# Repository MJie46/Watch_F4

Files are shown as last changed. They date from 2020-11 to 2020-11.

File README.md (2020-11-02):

# Watch_F4
>
#### 尺寸 40x36mm
#### STM32F405RGT6
#### IP5306+MP20045
#### MPU6050
#### W25Q128JVS
#### 蓝牙主从一体模块
#### 1.44寸SPI屏
#### 背面MAX30102，用作血氧检测
#### 背面引出4个按钮引脚

### 3D打印外壳
##### 本来想做成像外面卖的智能手表使用触电充电，再配上一个充电的底壳，但尝试后发现手工焊接接触平面很难4个触点在同一平面上，改用type-c接口，通过type-c烧录和串口调试

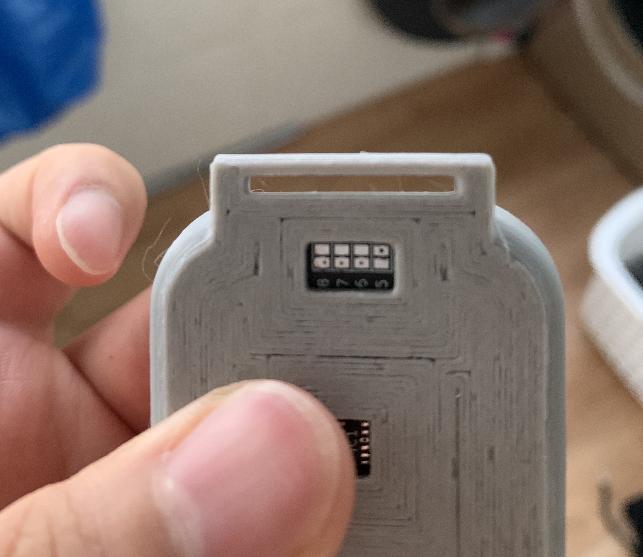
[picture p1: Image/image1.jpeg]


####第一版做好的大概，码代码中...
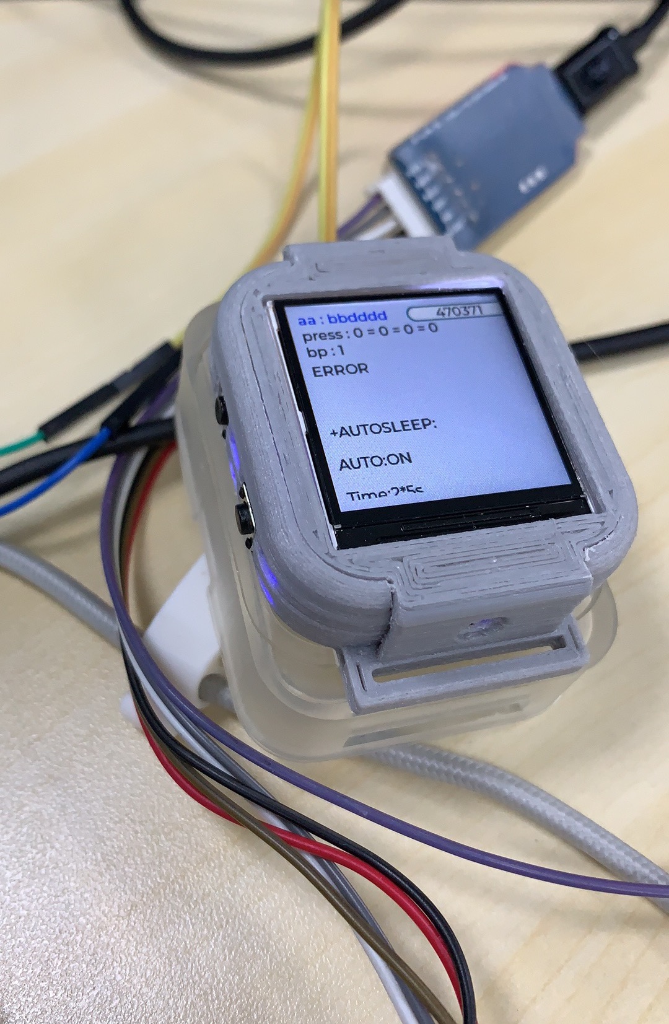
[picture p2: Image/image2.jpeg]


### 系统FreeRTOS，具体功能还没完善，待填...

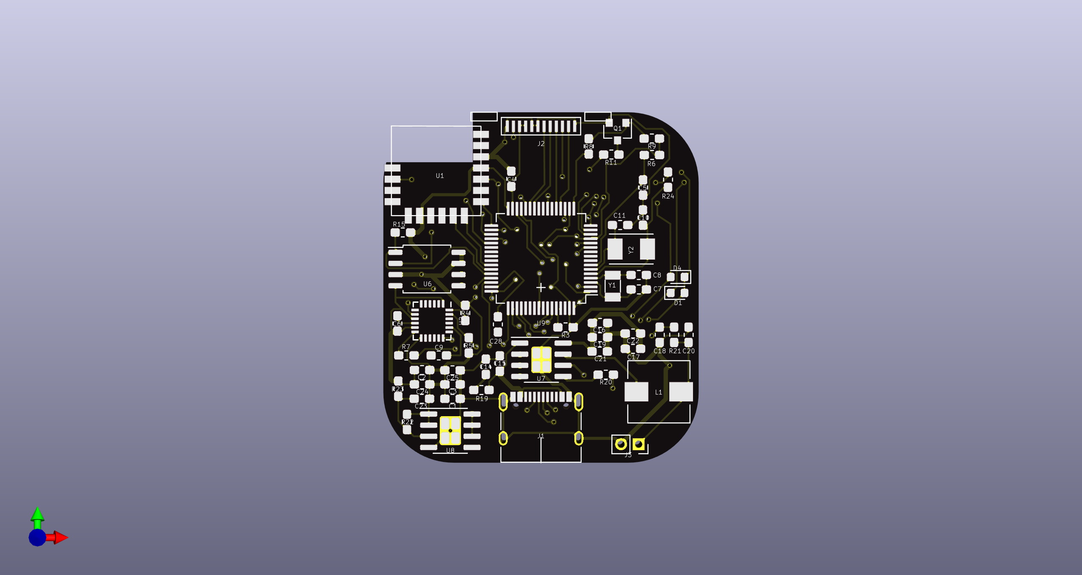
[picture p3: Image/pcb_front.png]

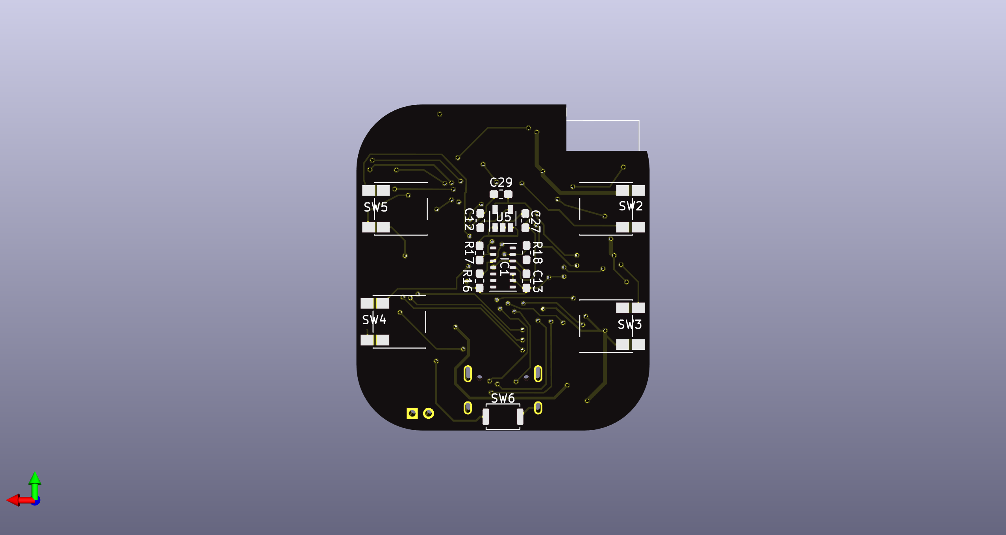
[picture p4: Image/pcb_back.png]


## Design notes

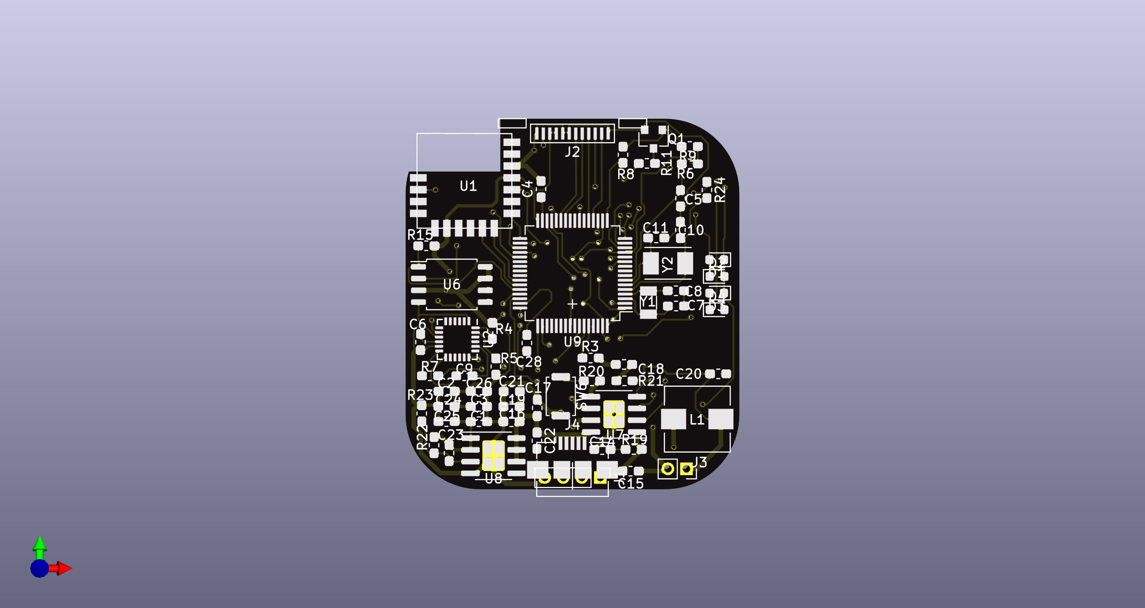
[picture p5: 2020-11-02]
Watch_F4.png

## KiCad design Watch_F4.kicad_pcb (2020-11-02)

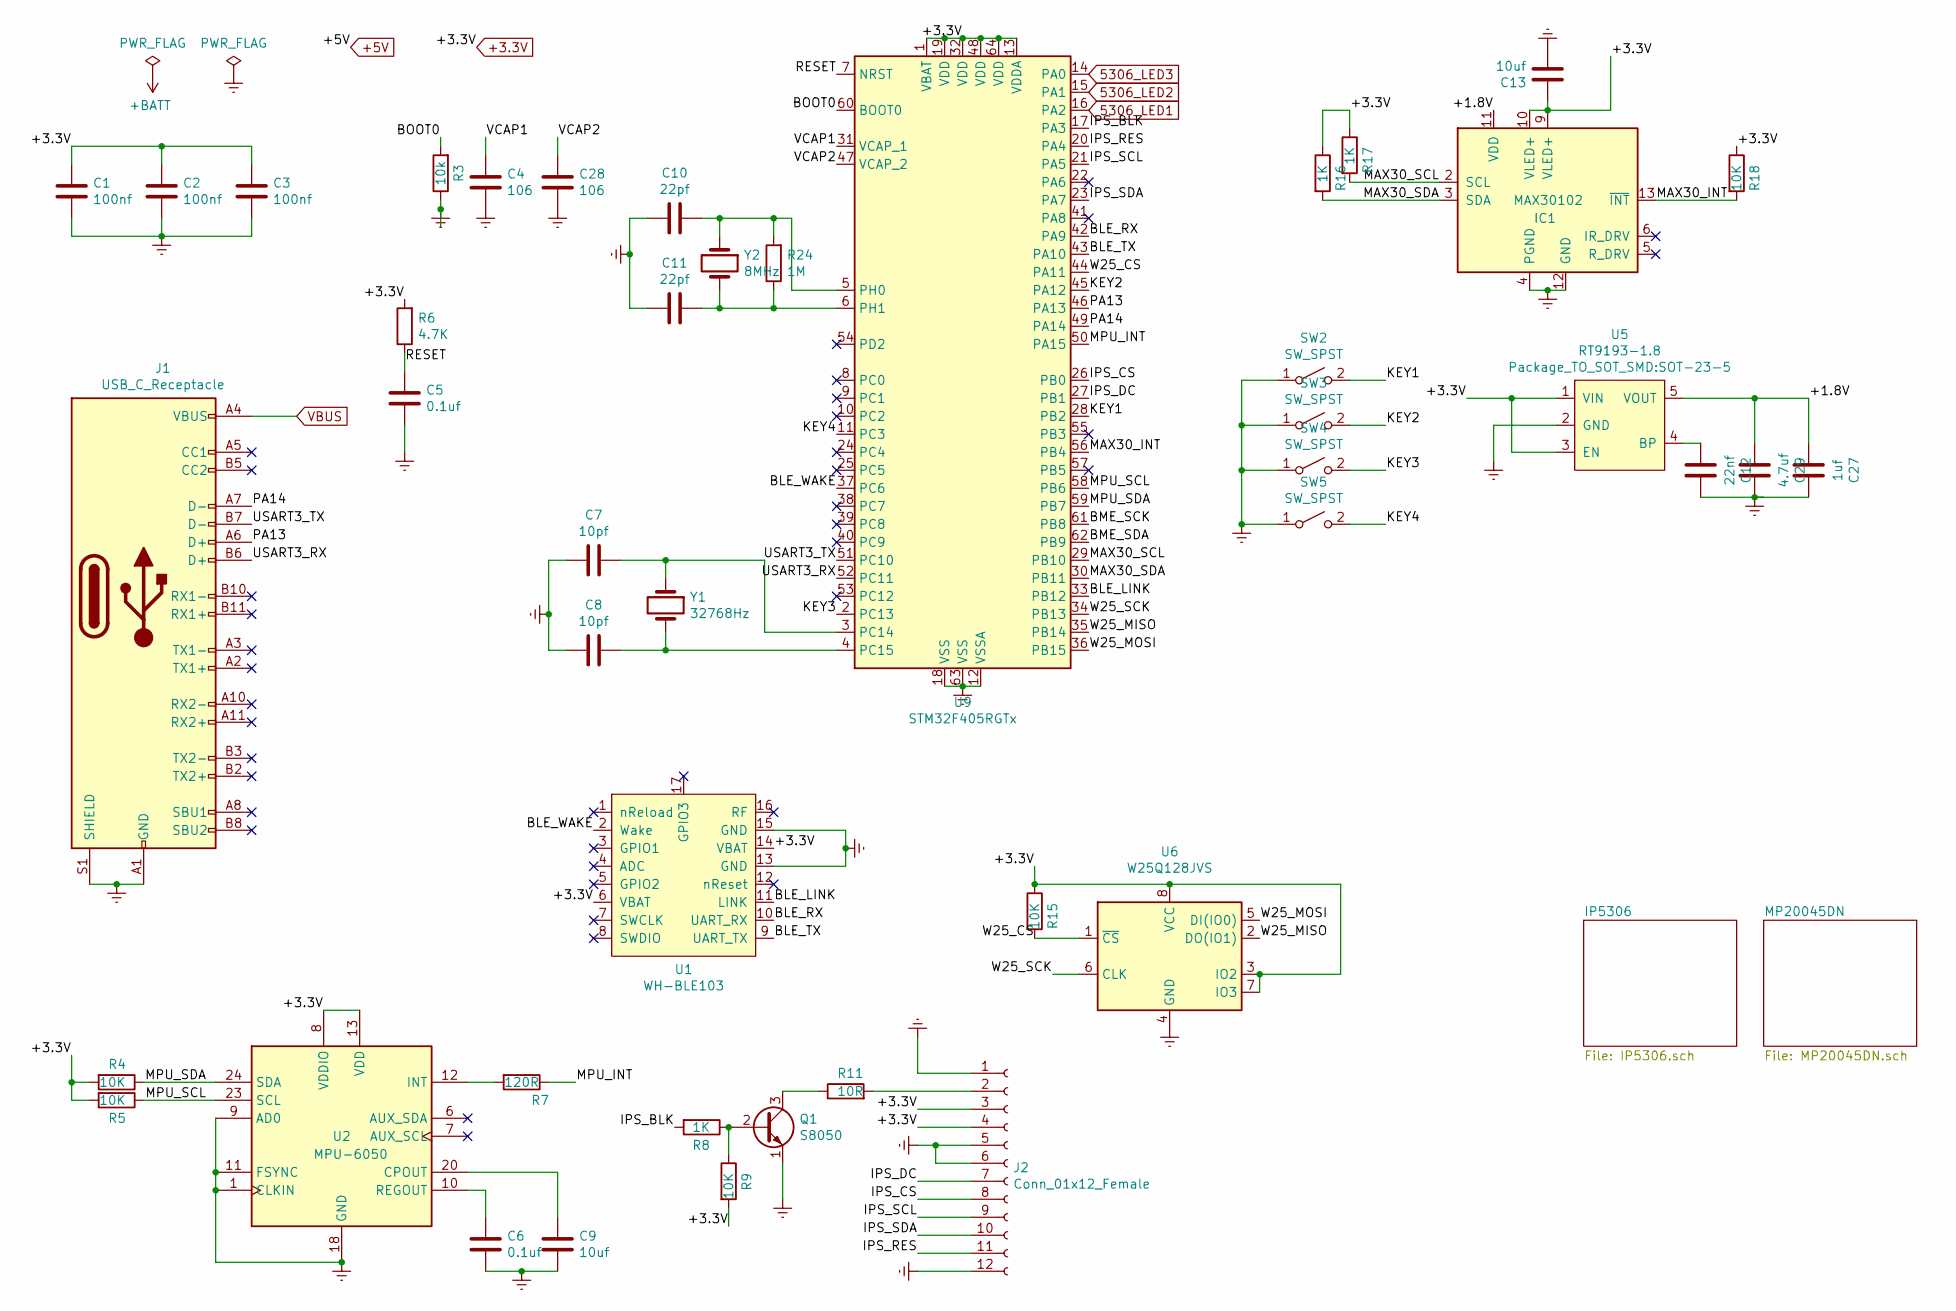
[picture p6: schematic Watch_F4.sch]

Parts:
C1, C2, C3: 100nf; C_0603_1608Metric_Pad1.05x0.95mm_HandSolder
C4, C28: 106; C_0603_1608Metric_Pad1.05x0.95mm_HandSolder
C5, C6: 0.1uf; C_0603_1608Metric_Pad1.05x0.95mm_HandSolder
C7, C8: 10pf; C_0603_1608Metric_Pad1.05x0.95mm_HandSolder
C9, C13: 10uf; C_0603_1608Metric_Pad1.05x0.95mm_HandSolder
C10, C11: 22pf; C_0603_1608Metric_Pad1.05x0.95mm_HandSolder
C12: 22nf; C_0603_1608Metric_Pad1.05x0.95mm_HandSolder
C27: 1uf; C_0603_1608Metric_Pad1.05x0.95mm_HandSolder
C29: 4.7uf; C_0603_1608Metric_Pad1.05x0.95mm_HandSolder
IC1: MAX30102; Maxim_OLGA-14_3.3x5.6mm_P0.8mm
J1: USB_C_Receptacle; USB_C_Receptacle_XKB_U262-16XN-4BVC11
J2: Conn_01x12_Female; FPC1x12-0.7
Q1: S8050; SOT-23-s8050
R3: 10k; R_0603_1608Metric_Pad1.05x0.95mm_HandSolder
R4, R5, R9, R15, R18: 10K; R_0603_1608Metric_Pad1.05x0.95mm_HandSolder
R6: 4.7K; R_0603_1608Metric_Pad1.05x0.95mm_HandSolder
R7: 120R; R_0603_1608Metric_Pad1.05x0.95mm_HandSolder
R8, R16, R17: 1K; R_0603_1608Metric_Pad1.05x0.95mm_HandSolder
R11: 10R; R_0603_1608Metric_Pad1.05x0.95mm_HandSolder
R24: 1M; R_0603_1608Metric_Pad1.05x0.95mm_HandSolder
SW2, SW3, SW4, SW5: SW_SPST; SW_SPST_PTS645
U1: WH-BLE103
U2: MPU-6050; InvenSense_QFN-24_4x4mm_P0.5mm
U5: RT9193-1.8; SOT-23-5
U6: W25Q128JVS; SOIC-8_5.23x5.23mm_P1.27mm
U9: STM32F405RGTx; LQFP-64_10x10mm_P0.5mm
Y1: 32768Hz; Crystal_SMD_3215-2Pin_3.2x1.5mm
Y2: 8MHz; Crystal_SMD_TXC_7A-2Pin_5x3.2mm

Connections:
5306_LED1: U9.16 (PA2); also elsewhere on the board
5306_LED2: U9.15 (PA1); also elsewhere on the board
5306_LED3: U9.14 (PA0); also elsewhere on the board
+3.3V: C1.1, C2.1, C3.1, C13.1, IC1.9 (VLED+), IC1.10 (VLED+), J2.3, J2.4, R4.2, R5.2, R6.2, R9.2, R15.1, R16.1, R17.1, R18.1, U1.6 (VBAT), U1.14 (VBAT), U2.8 (VDDIO), U2.13 (VDD), U5.1 (VIN), U5.3 (EN), U6.3 (IO2), U6.7 (IO3), U6.8 (VCC), U9.1 (VBAT), U9.13 (VDDA), U9.19 (VDD), U9.32 (VDD), U9.48 (VDD), U9.64 (VDD); also elsewhere on the board
/+1.8V: C27.2, C29.2, IC1.11 (VDD), U5.5 (VOUT)
/BLE_LINK: U1.11 (LINK), U9.33 (PB12)
/BLE_RX: U1.10 (UART_RX), U9.42 (PA9)
/BLE_TX: U1.9 (UART_TX), U9.43 (PA10)
/BLE_WAKE: U1.2 (Wake), U9.37 (PC6)
/BME_SCK: U9.61 (PB8)
/BME_SDA: U9.62 (PB9)
/BOOT0: R3.2, U9.60 (BOOT0)
/IPS_BLK: R8.2, U9.17 (PA3)
/IPS_CS: J2.8, U9.26 (PB0)
/IPS_DC: J2.7, U9.27 (PB1)
/IPS_RES: J2.11, U9.20 (PA4)
/IPS_SCL: J2.9, U9.21 (PA5)
/IPS_SDA: J2.10, U9.23 (PA7)
/KEY1: SW2.2 (B), U9.28 (PB2)
/KEY2: SW3.2 (B), U9.45 (PA12)
/KEY3: SW4.2 (B), U9.2 (PC13)
/KEY4: SW5.2 (B), U9.11 (PC3)
/MAX30_INT: IC1.13 (~INT), R18.2, U9.56 (PB4)
/MAX30_SCL: IC1.2 (SCL), R17.2, U9.29 (PB10)
/MAX30_SDA: IC1.3 (SDA), R16.2, U9.30 (PB11)
/MPU_INT: R7.1, U9.50 (PA15)
/MPU_SCL: R5.1, U2.23 (SCL), U9.58 (PB6)
/MPU_SDA: R4.1, U2.24 (SDA), U9.59 (PB7)
/PA13: J1.A6 (D+), U9.46 (PA13)
/PA14: J1.A7 (D-), U9.49 (PA14)
/RESET: C5.1, R6.1, U9.7 (NRST)
/UART4_RX: J1.B6 (D+), U9.52 (PC11)
/UART4_TX: J1.B7 (D-), U9.51 (PC10)
/VCAP1: C4.1, U9.31 (VCAP_1)
/VCAP2: C28.1, U9.47 (VCAP_2)
/W25_CS: R15.2, U6.1 (~CS), U9.44 (PA11)
/W25_MISO: U6.2 (DO(IO1)), U9.35 (PB14)
/W25_MOSI: U6.5 (DI(IO0)), U9.36 (PB15)
/W25_SCK: U6.6 (CLK), U9.34 (PB13)
Earth: C1.2, C2.2, C3.2, C4.2, C5.2, C6.2, C7.2, C8.2, C9.2, C10.2, C11.2, C12.1, C13.2, C27.1, C28.2, C29.1, IC1.4 (PGND), IC1.12 (GND), J1.A1 (GND), J1.A12 (GND), J1.B1 (GND), J1.B12 (GND), J1.S1 (SHIELD), J2.1, J2.5, J2.6, J2.12, Q1.1 (E), R3.1, SW2.1 (A), SW3.1 (A), SW4.1 (A), SW5.1 (A), U1.13 (GND), U1.15 (GND), U2.1 (CLKIN), U2.9 (AD0), U2.11 (FSYNC), U2.18 (GND), U5.2 (GND), U6.4 (GND), U9.12 (VSSA), U9.18 (VSS), U9.63 (VSS); also elsewhere on the board
unnamed: C6.1, U2.10 (REGOUT)
unnamed: C7.1, U9.3 (PC14), Y1.1
unnamed: C8.1, U9.4 (PC15), Y1.2
unnamed: C9.1, U2.20 (CPOUT)
unnamed: C10.1, R24.2, U9.5 (PH0), Y2.1
unnamed: C11.1, R24.1, U9.6 (PH1), Y2.2
unnamed: C12.2, U5.4 (BP)
unnamed: J2.2, R11.2
unnamed: Q1.2 (B), R8.1, R9.1
unnamed: Q1.3 (C), R11.1
unnamed: R7.2, U2.12 (INT)
VBUS: J1.A4 (VBUS), J1.A9 (VBUS), J1.B4 (VBUS), J1.B9 (VBUS); also elsewhere on the board

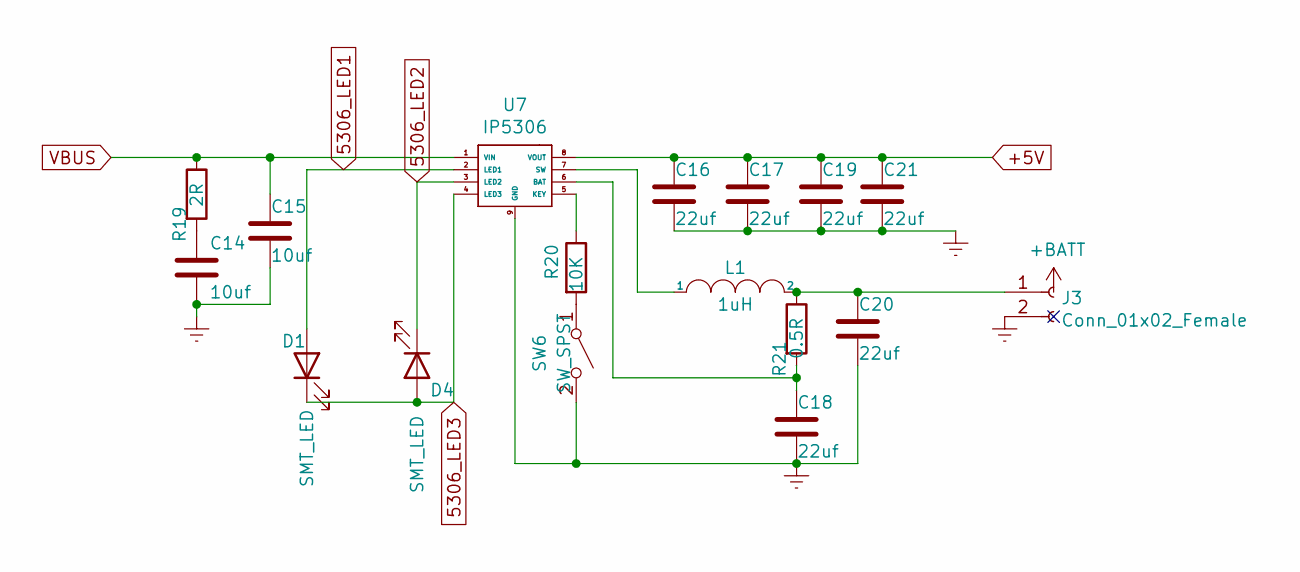
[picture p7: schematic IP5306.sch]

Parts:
C14, C15: 10uf; C_0603_1608Metric_Pad1.05x0.95mm_HandSolder
C16, C17, C18, C19, C20, C21: 22uf; C_0603_1608Metric_Pad1.05x0.95mm_HandSolder
D1, D4: SMT_LED; LED_0603_1608Metric
J3: Conn_01x02_Female; PinSocket_1x02_P2.00mm_Vertical
L1: 1uH; L_Wuerth_HCI-7030
R19: 2R; R_0603_1608Metric_Pad1.05x0.95mm_HandSolder
R20: 10K; R_0603_1608Metric_Pad1.05x0.95mm_HandSolder
R21: 0.5R; R_0603_1608Metric_Pad1.05x0.95mm_HandSolder
SW6: SW_SPST; SW_Push_SPST_NO_Alps_SKRK
U7: IP5306; SOIC-8-1EP_3.9x4.9mm_P1.27mm_EP2.29x3mm

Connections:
5306_LED1: D1.2 (A), U7.2 (LED1); also elsewhere on the board
5306_LED2: D4.1 (K), U7.3 (LED2); also elsewhere on the board
5306_LED3: D1.1 (K), D4.2 (A), U7.4 (LED3); also elsewhere on the board
+5V: C16.1, C17.1, C19.1, C21.1, U7.8 (VOUT); also elsewhere on the board
Earth: C14.2, C15.2, C16.2, C17.2, C18.2, C19.2, C20.2, C21.2, J3.2, SW6.2 (B), U7.9 (GND); also elsewhere on the board
unnamed: C14.1, R19.2
unnamed: C18.1, R21.2, U7.6 (BAT)
unnamed: C20.1, J3.1, L1.2, R21.1
unnamed: L1.1, U7.7 (SW)
unnamed: R20.1, U7.5 (KEY)
unnamed: R20.2, SW6.1 (A)
VBUS: C15.1, R19.1, U7.1 (VIN); also elsewhere on the board

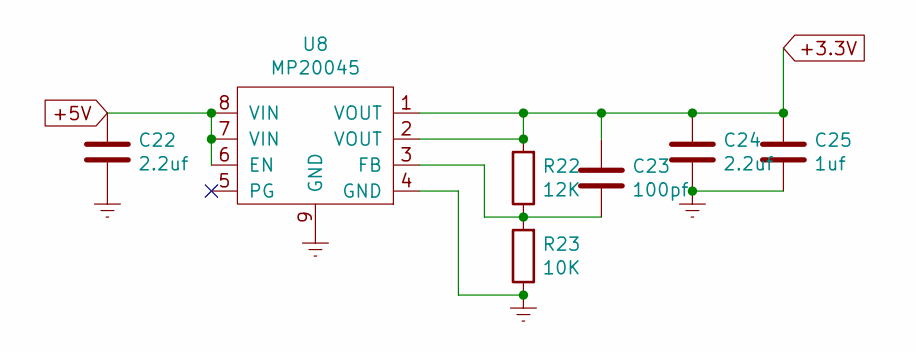
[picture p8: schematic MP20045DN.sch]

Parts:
C22, C24: 2.2uf; C_0603_1608Metric_Pad1.05x0.95mm_HandSolder
C23: 100pf; C_0603_1608Metric_Pad1.05x0.95mm_HandSolder
C25: 1uf; C_0603_1608Metric_Pad1.05x0.95mm_HandSolder
R22: 12K; R_0603_1608Metric_Pad1.05x0.95mm_HandSolder
R23: 10K; R_0603_1608Metric_Pad1.05x0.95mm_HandSolder
U8: MP20045; SOIC-8-1EP_3.9x4.9mm_P1.27mm_EP2.41x3.3mm

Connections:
+3.3V: C23.1, C24.1, C25.1, R22.2, U8.1 (VOUT), U8.2 (VOUT); also elsewhere on the board
+5V: C22.1, U8.6 (EN), U8.7 (VIN), U8.8 (VIN); also elsewhere on the board
Earth: C22.2, C24.2, C25.2, R23.1, U8.4 (GND), U8.9 (GND); also elsewhere on the board
unnamed: C23.2, R22.1, R23.2, U8.3 (FB)

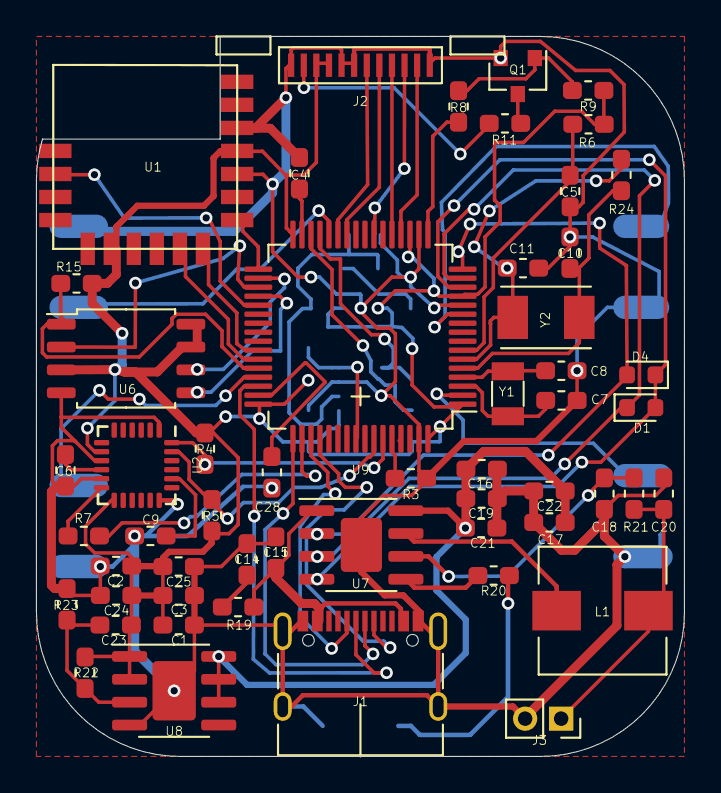
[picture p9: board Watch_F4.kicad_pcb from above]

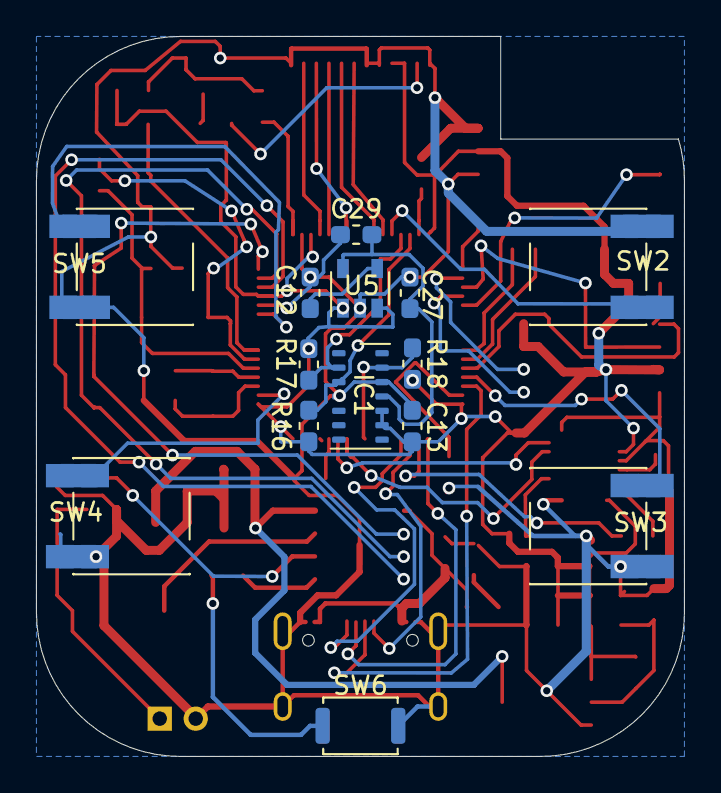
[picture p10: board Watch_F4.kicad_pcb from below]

Board: 2 copper layers, 36.0 x 40.0 mm, 68 parts (14 on the bottom side), 58 nets.
